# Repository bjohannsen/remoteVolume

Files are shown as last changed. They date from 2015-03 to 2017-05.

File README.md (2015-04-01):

# remoteVolume
An AVR-based IR controlled audio volume controller.
Primary purpose was to use active studio monitors with a TV without a fitting AV receiver.

# Features
* ATmega168 controller
* Volume controlling via <a href="http://www.ti.com/lit/ds/symlink/pga2311.pdf" target="_blank">TI PGA2311</a>
* Working with most IR protocols thanks to <a href="http://www.mikrocontroller.net/articles/IRMP" target="_blank">IRMP</a> library
* Two selectable input sources
* Switch output to control a subwoofer
* Display current volume by a ring of LEDs and a motorized pot.

#Caveats
* External power supply needed, for example <a href="http://www.meanwell.com/search/NET-35/NET-35-spec.pdf" target="_blank">Mean Well NET-35B</a>

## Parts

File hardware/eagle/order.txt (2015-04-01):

Parts
Front Panel:							
#	Value		Package		Reichelt
2	74HCT595N	DIL16    	74HC 595
16	1.5k		R-EU_0207/7	METALL 1,5K
1   	100		R-EU_0207/7	METALL 100
1   	MA10-2      	MA10-2		SL 2X10G 2,54
16	LED 3mm, low current		LED 3MM 2MA GN
1	TSOP1738	TSOP17XX	TSOP 31238

Main:
#	Value		Package		Reichelt
10      100n           	C025-025X050	X7R-2,5 100N
2	220u		E2,5-6		RAD FR 220/16
2	22p		C025-025X050	KERKO 22P
7	47u		E2,5-6		RAD FR 47/25
2	3.3n		C050-055X075	FKP-2 3,3N
2	470n		C5B3.5		MKS-2 470N
2	1000u		E3,5-8		RAD FR 1.000/10
2	100u		E2,5-5		RAD FR 100/16
11	--		NRJ4HF		NEUTRIK NR-J4HF
4	DIODE1N4148	DO-35		1N 4148
1	MEGA168-P	DIL28-3		ATMEGA 168-20DIP    
1	L293D		DIL16		L 293 D
1	7805		TO220V		µA 7805
1	7905		TO220V		µA 7905
1	OPA2132P	DIL08		OPA 2132 PA
1	PGA2311P	DIL16		(--> eBay)
1	--		1X04/90		MPE 087-1-004
1	AVR-ISP-10	1x10		WSL 10G
2	--		FTR-B4C		FTR-B4CA 4,5V
1	20MHz		HC49/S		20,0000-HC49U-S
2	10k		0207/7		METALL 10,0K
4	2k		0207/7		METALL 2,00K
2	220k		0207/7		METALL 220K
1	100k		0207/7		METALL 100K
2	27k		0207/7		METALL 27,0K
1	33		0207/7		METALL 33,0
1	--		FE10-2W		BL 2X10W 2,54
2	BC337		TO92		BC 337-40
1	--		RK16816MG	(--> conrad: 442068-62)
1	RCA-4-117-01	RCA-4-117-01	CBP 4
1	RCA-2		RCA-2		CBP 2

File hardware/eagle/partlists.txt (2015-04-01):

Parts
Front Panel:
IC1      74HCT595N      DIL16    
IC2      74HCT595N      DIL16    
R1       1.5k           0207/7 
R2       1.5k           0207/7 
R3       1.5k           0207/7 
R4       1.5k           0207/7 
R5       1.5k           0207/7
R6       1.5k           0207/7
R7       1.5k           0207/7
R8       1.5k           0207/7
R9       1.5k           0207/7
R10      1.5k           0207/7
R11      1.5k           0207/7
R12      1.5k           0207/7
R13      1.5k           0207/7
R14      1.5k           0207/7
R15      1.5k           0207/7
R16      1.5k           0207/7
R17      100            0207/7
SV2      --             MA10-2
U$2      --		16x3mm LED low current
U$3      TSOP1738       TSOP17XX

Main:
C1       100n           C025-025X050
C2       100n           C025-025X050
C3       220u           E2,5-6      
C4       22p            C025-025X050
C5       22p            C025-025X050
C6       100n           C025-025X050
C7       100n           C025-025X050
C8       47u            E2,5-6      
C9       100n           C025-025X050
C10      100n           C025-025X050
C11      3.3n           C050-055X075
C12      470n           C5B3.5      
C13      470n           C5B3.5      
C14      3.3n           C050-055X075
C15      220u           E2,5-6      
C16      1000u          E3,5-8      
C17      100n           C025-025X050
C18      100u           E2,5-5      
C19      100u           E2,5-5      
C20      100n           C025-025X050
C21      47u            E2,5-5      
C22      100u           E2,5-5      
C23      100n           C025-025X050
C24      47u            E2,5-5      
C25      100n           C025-025X050
C26      1000u          E3,5-8      
C28      47u            E2,5-5      
C29      47u            E2,5-5      
C30      47u            E2,5-5      
C31      47u            E2,5-5      
CN1      NRJ4HF         NRJ4HF      
D5       1N4148    	DO-35       
D6       1N4148         DO-35
D7       1N4148    	DO-35       
D8       1N4148         DO35
IC1      MEGA168-P	DIL28-3     
IC2      L293D          DIL16       
IC3      7805           TO220V      
IC4      OPA2132P       DIL08       
IC5      PGA2311P       DIL16       
IC7      7905           TO220V      
JP1      --             1X04/90     
JP4      --	    	AVR-ISP-10  
K1       --		FTR-B4C
K2       --		FTR-B4C
Q1       20MHz          HC49/S      
R2       10k            0207/7      
R4       2k             0207/7      
R6       2k             0207/7      
R7       220k           0207/7      
R8       220k           0207/7      
R9       2k             0207/7      
R10      100k           0207/7      
R11      27k            0207/7      
R12      2k             0207/7     
R13      27k            0207/7     
R14      39             0207/7     
R15      39             0207/7     
R16      10k            0207/7     
SV2      --             FE10-2W    
T2       BC337          TO92       
T3       BC337          TO92       
U$1      --		RK16816MG  
X_IN     --		RCA-4-117-01
X_OUT    --		RCA-2

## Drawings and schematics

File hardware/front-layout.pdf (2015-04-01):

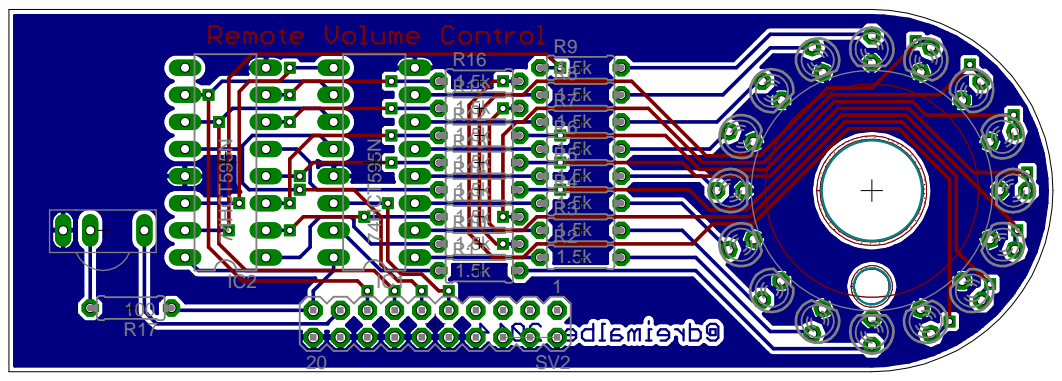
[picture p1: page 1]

1.5k R13 | R6 1.5k
1.5k R14 | 1.5k R5
R11 1.5k | R4 1.5k

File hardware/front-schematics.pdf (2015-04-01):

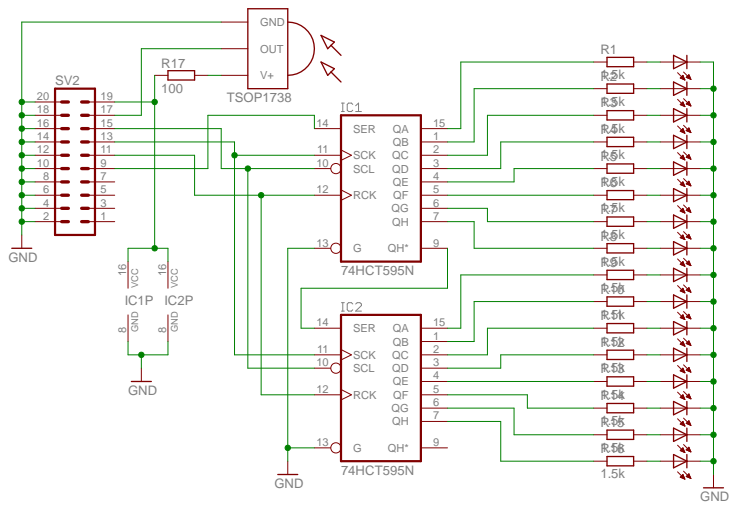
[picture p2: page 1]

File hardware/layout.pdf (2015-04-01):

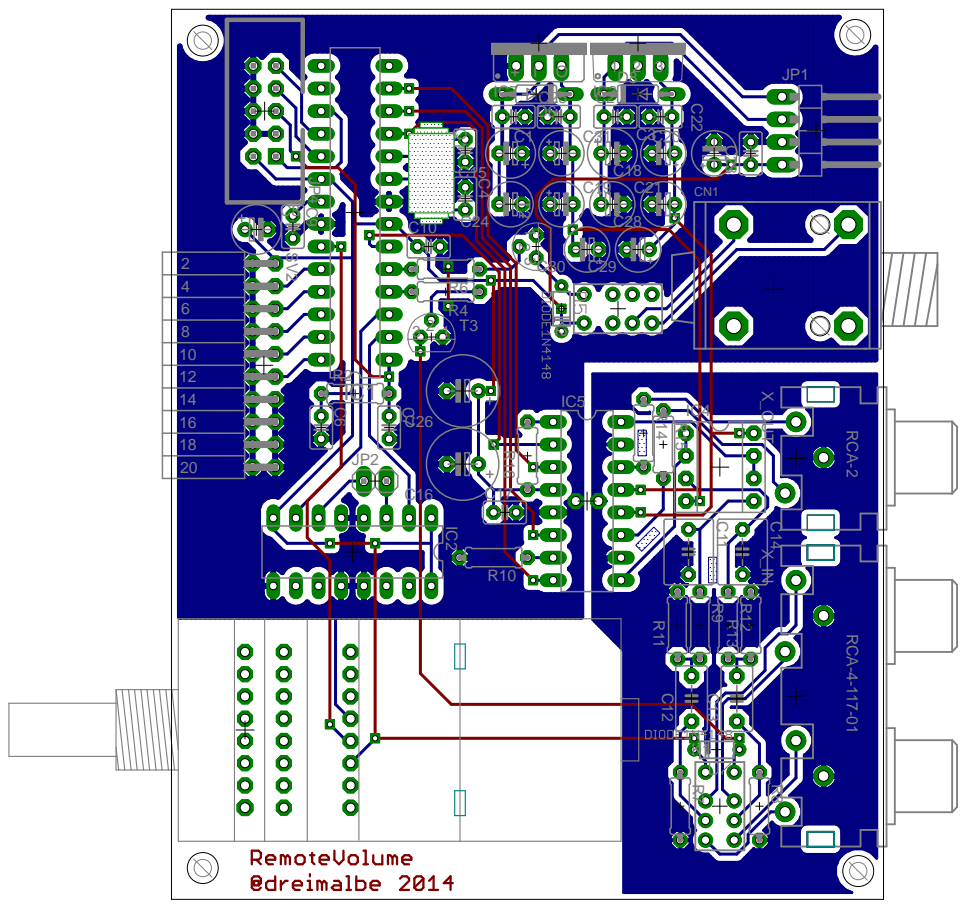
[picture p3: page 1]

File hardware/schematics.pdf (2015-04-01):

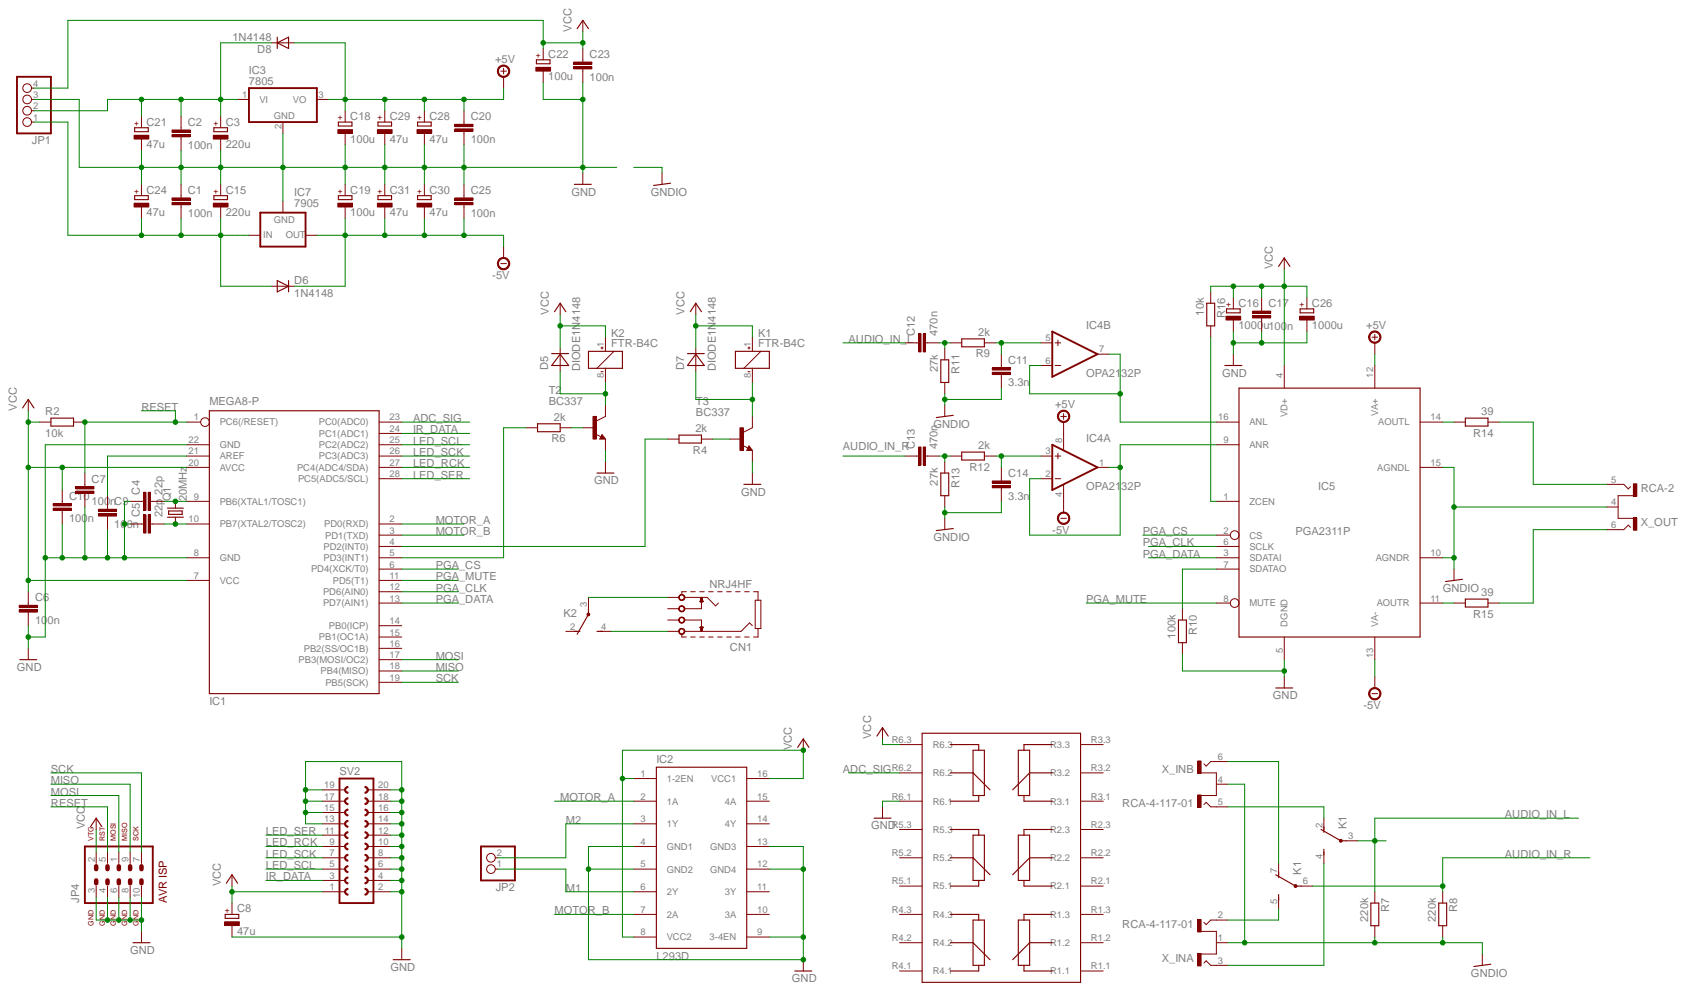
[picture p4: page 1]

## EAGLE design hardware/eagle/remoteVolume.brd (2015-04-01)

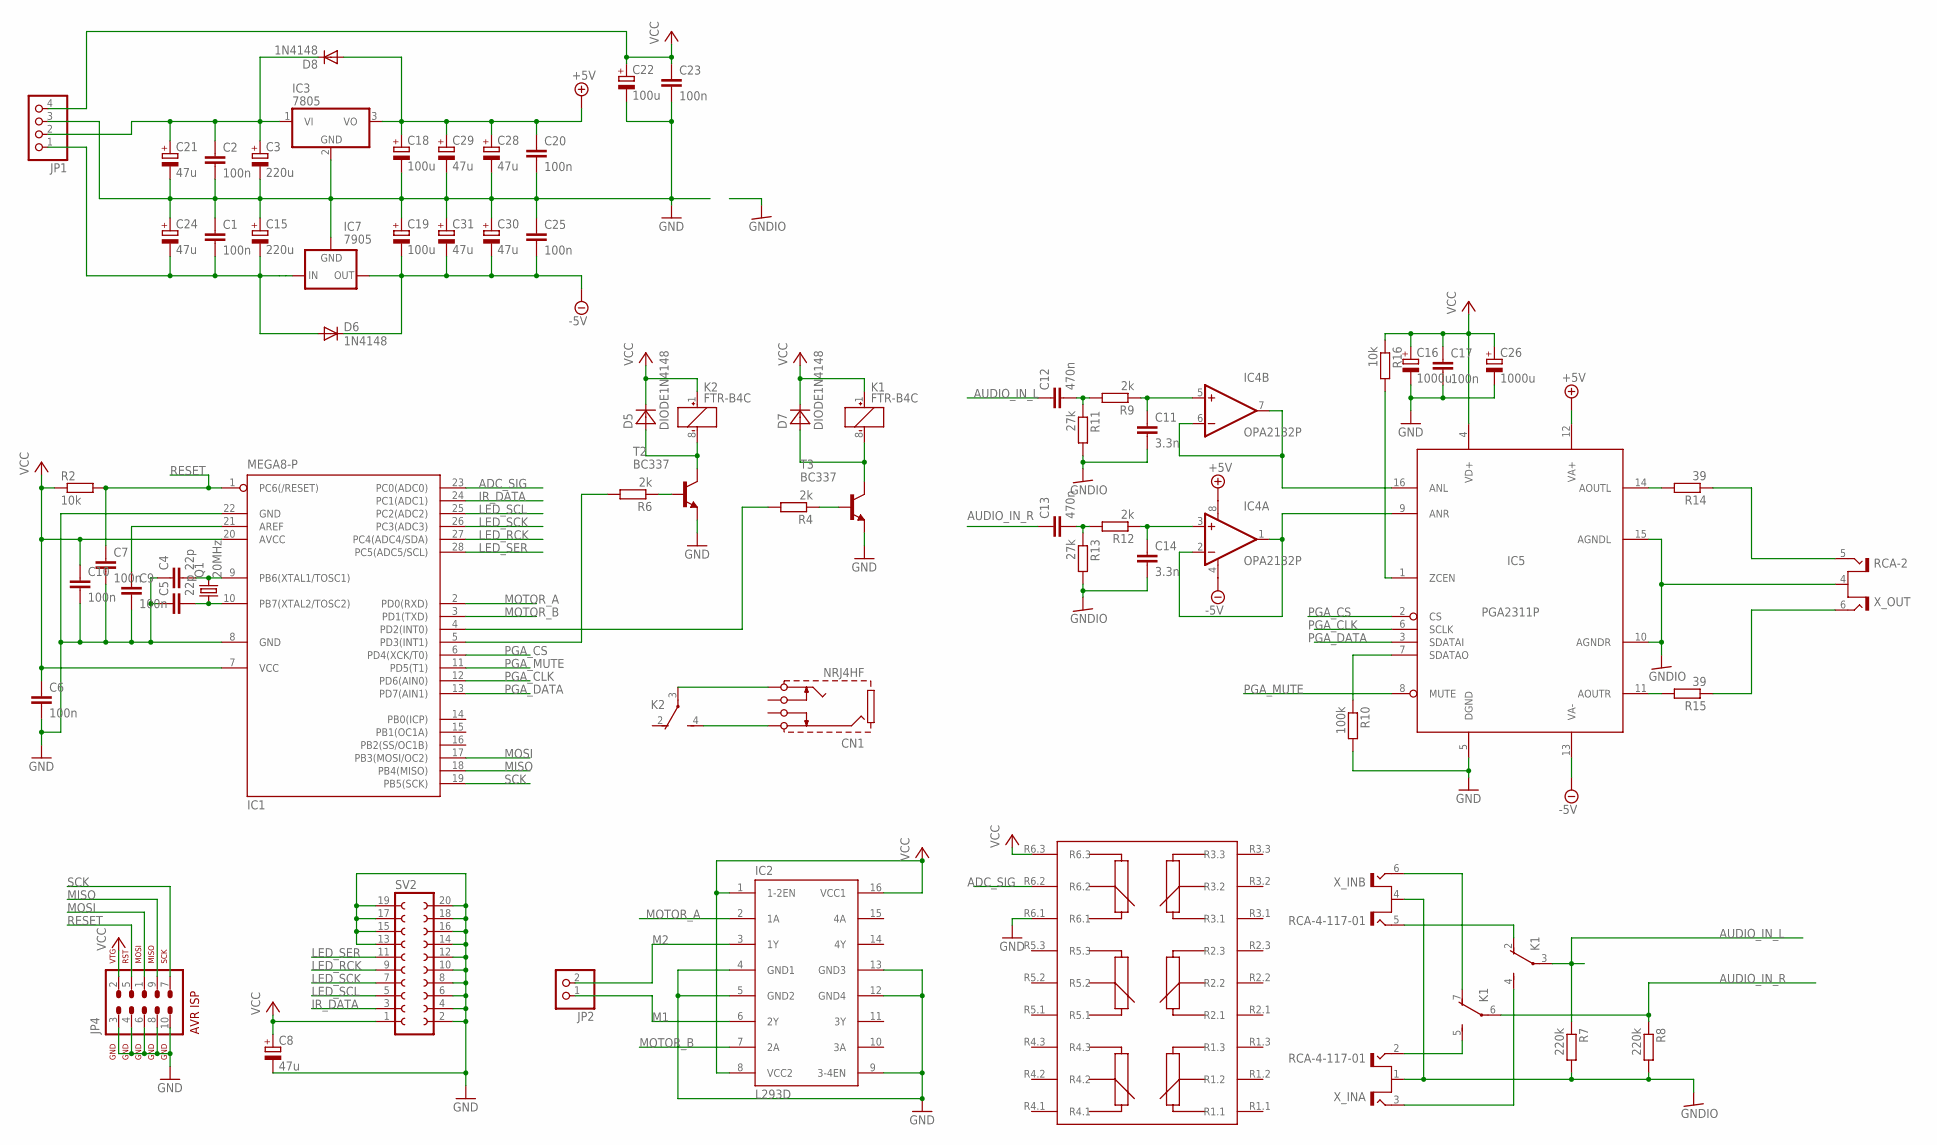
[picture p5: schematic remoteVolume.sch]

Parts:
C1, C2, C6, C7, C9, C10, C17, C20, C23, C25: 100n; C025-025X050
C3, C15: 220u; E2,5-6
C4, C5: 22p; C025-025X050
C8: 47u; E2,5-6
C11, C14: 3.3n; C050-055X075
C12, C13: 470n; C5B3.5
C16, C26: 1000u; E3,5-8
C18, C19, C22: 100u; E2,5-5
C21, C24, C28, C29, C30, C31: 47u; E2,5-5
CN1: NRJ4HF
D5, D7: DIODE1N4148; DO-35
D6, D8: 1N4148; DO35-7
IC1: MEGA8-P; DIL28-3
IC2: L293D; DIL16
IC3: 7805; TO220V
IC4: OPA2132P; DIL08
IC5: PGA2311P; DIL16
IC7: 7905; 79XXS
JP1: PINHD-1X4/90; 1X04/90
JP2: PINHD-1X2; 1X02
JP4: AVR-ISP-10
K1, K2: FTR-B4C
Q1: 20MHz; HC49/S
R2, R16: 10k; 0207/7
R4, R6, R9, R12: 2k; 0207/7
R7, R8: 220k; 0207/7
R10: 100k; 0207/7
R11, R13: 27k; 0207/7
R14, R15: 39; 0207/7
SV2: FE10-2W
T2, T3: BC337; TO92
U$1: RK16816MG
X_IN: RCA-4-117-01
X_OUT: RCA-2

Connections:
+5V: C18.+, C20.1, C28.+, C29.+, D8.A, IC3.3 (VO), IC4.8 (V+), IC5.12 (VA+)
-5V: C19.-, C25.2, C30.-, C31.-, D6.C, IC4.4 (V-), IC5.13 (VA-), IC7.OUT
ADC_SIG: IC1.23 (PC0(ADC0)), U$1.R6.2
AUDIO_IN_L: C12.1, K1.3, R7.1
AUDIO_IN_R: C13.1, K1.6, R8.1
GND: C1.1, C2.2, C3.-, C4.1, C5.1, C6.2, C7.2, C8.-, C9.2, C10.2, C15.+, C16.-, C17.2, C18.-, C19.+, C20.2, C21.-, C22.-, C23.2, C24.+, C25.1, C26.-, C28.-, C29.-, C30.+, C31.+, IC1.8 (GND), IC1.22 (GND), IC2.4 (GND1), IC2.5 (GND2), IC2.9 (3-4EN), IC2.12 (GND4), IC2.13 (GND3), IC3.2 (GND), IC5.5 (DGND), IC7.GND, JP1.3, JP4.3, JP4.4, JP4.6, JP4.8, JP4.10, R10.2, SV2.2, SV2.4, SV2.6, SV2.8, SV2.10, SV2.12, SV2.13, SV2.14, SV2.15, SV2.16, SV2.17, SV2.18, SV2.19, SV2.20, T2.1 (E), T3.1 (E), U$1.R6.1
GNDIO: C11.2, C14.2, IC5.10 (AGNDR), IC5.15 (AGNDL), R7.2, R8.2, R11.2, R13.2, X_IN.1 (S), X_IN.4 (S), X_OUT.4 (S)
IR_DATA: IC1.24 (PC1(ADC1)), SV2.3
LED_RCK: IC1.27 (PC4(ADC4/SDA)), SV2.9
LED_SCK: IC1.26 (PC3(ADC3)), SV2.7
LED_SCL: IC1.25 (PC2(ADC2)), SV2.5
LED_SER: IC1.28 (PC5(ADC5/SCL)), SV2.11
M1: IC2.6 (2Y), JP2.1
M2: IC2.3 (1Y), JP2.2
MISO: IC1.18 (PB4(MISO)), JP4.9
MOSI: IC1.17 (PB3(MOSI/OC2)), JP4.1
MOTOR_A: IC1.2 (PD0(RXD)), IC2.2 (1A)
MOTOR_B: IC1.3 (PD1(TXD)), IC2.7 (2A)
unnamed: CN1.SLEEVE, K2.4 (S)
unnamed: IC4.1 (OUT), IC4.2 (-IN), IC5.9 (ANR)
unnamed: C2.1, C3.+, C21.+, D8.C, IC3.1 (VI), JP1.2
unnamed: C1.2, C15.-, C24.-, D6.A, IC7.IN, JP1.1
unnamed: K1.5 (S), X_IN.2 (T1)
unnamed: D7.+, K1.8 (-), T3.3 (C)
unnamed: C4.2, IC1.9 (PB6(XTAL1/TOSC1)), Q1.2
unnamed: C5.2, IC1.10 (PB7(XTAL2/TOSC2)), Q1.1
unnamed: R4.1, T3.2 (B)
unnamed: IC1.4 (PD2(INT0)), R4.2
unnamed: K1.7 (O), X_IN.6 (T2)
unnamed: IC1.5 (PD3(INT1)), R6.2
unnamed: K1.2 (O), X_IN.5 (T1)
unnamed: R6.1, T2.2 (B)
unnamed: K1.4 (S), X_IN.3 (T2)
unnamed: D5.+, K2.8 (-), T2.3 (C)
unnamed: CN1.TIP, K2.3
unnamed: C9.1, IC1.21 (AREF)
unnamed: IC4.6 (-IN), IC4.7 (OUT), IC5.16 (ANL)
unnamed: C12.2, R9.2, R11.1
unnamed: C11.1, IC4.5 (+IN), R9.1
unnamed: C14.1, IC4.3 (+IN), R12.1
unnamed: R14.1, X_OUT.5 (T1)
unnamed: R15.1, X_OUT.6 (T2)
unnamed: C13.2, R12.2, R13.1
unnamed: IC5.7 (SDATAO), R10.1
unnamed: IC5.14 (AOUTL), R14.2
unnamed: IC5.11 (AOUTR), R15.2
unnamed: IC5.1 (ZCEN), R16.2
PGA_CLK: IC1.12 (PD6(AIN0)), IC5.6 (SCLK)
PGA_CS: IC1.6 (PD4(XCK/T0)), IC5.2 (CS)
PGA_DATA: IC1.13 (PD7(AIN1)), IC5.3 (SDATAI)
PGA_MUTE: IC1.11 (PD5(T1)), IC5.8 (MUTE)
RESET: C7.1, IC1.1 (PC6(/RESET)), JP4.5, R2.2
SCK: IC1.19 (PB5(SCK)), JP4.7
VCC: C6.1, C8.+, C10.1, C16.+, C17.1, C22.+, C23.1, C26.+, D5.-, D7.-, IC1.7 (VCC), IC1.20 (AVCC), IC2.1 (1-2EN), IC2.8 (VCC2), IC2.16 (VCC1), IC5.4 (VD+), JP1.4, JP4.2, K1.1 (+), K2.1 (+), R2.1, R16.1, SV2.1, U$1.R6.3

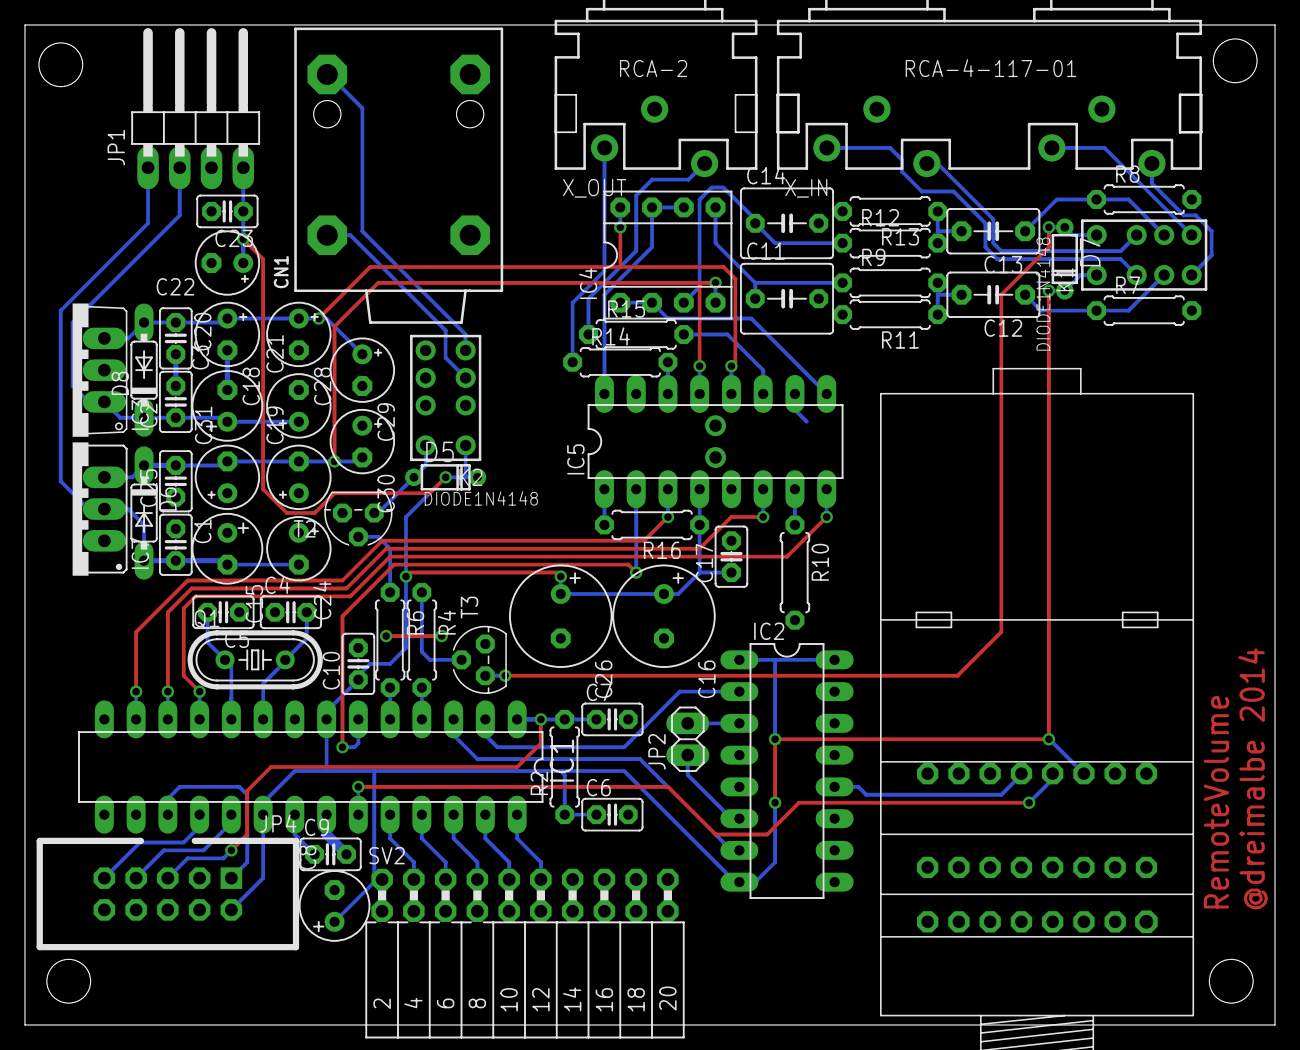
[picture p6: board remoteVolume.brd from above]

Board: 2 copper layers, 100.0 x 80.0 mm, 66 parts (0 on the bottom side), 54 nets.

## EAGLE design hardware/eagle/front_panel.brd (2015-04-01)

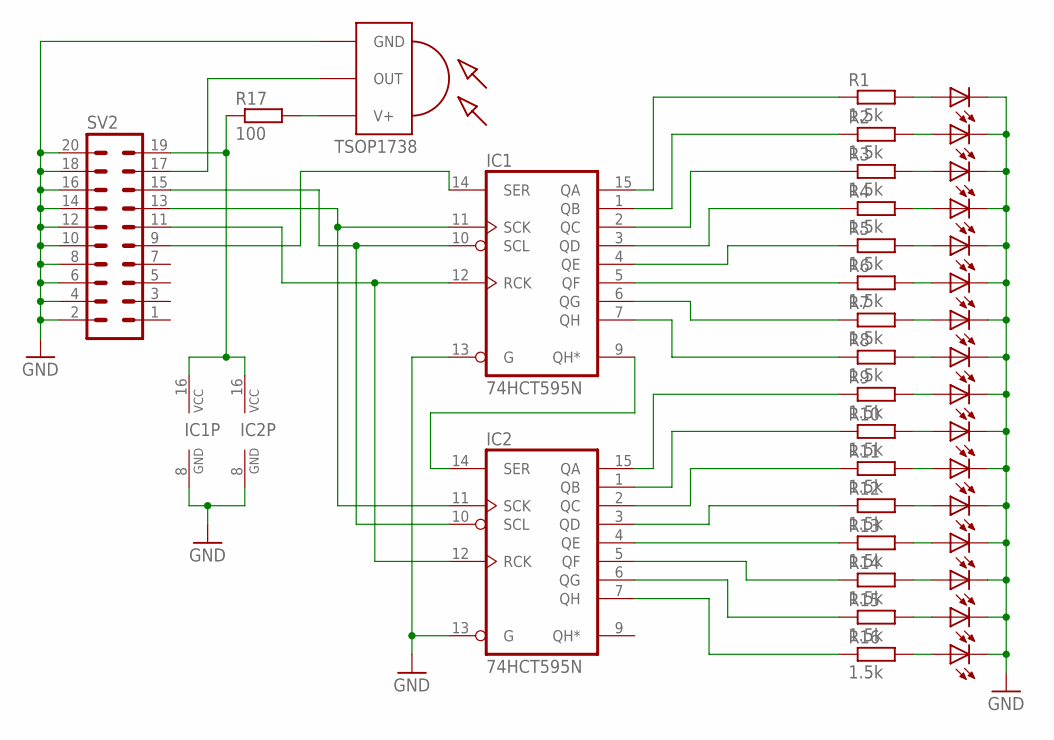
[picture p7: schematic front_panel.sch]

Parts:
IC1, IC2: 74HCT595N; DIL16
R1, R2, R3, R4, R5, R6, R7, R8, R9, R10, R11, R12, R13, R14, R15, R16: 1.5k; 0207/7
R17: 100; 0207/7
SV2: MA10-2
U$2: LED_RING_16; POTI_LED_RING16
U$3: TSOP1738; TSOP17XX

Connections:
GND: IC1.8 (GND), IC1.13 (G), IC2.8 (GND), IC2.13 (G), SV2.2, SV2.4, SV2.6, SV2.8, SV2.10, SV2.12, SV2.14, SV2.16, SV2.18, SV2.20, U$2.K0, U$2.K1, U$2.K2, U$2.K3, U$2.K4, U$2.K5, U$2.K6, U$2.K7, U$2.K8, U$2.K9, U$2.K10, U$2.K11, U$2.K12, U$2.K13, U$2.K14, U$2.K15, U$3.GND
unnamed: IC1.9 (QH*), IC2.14 (SER)
unnamed: R9.2, U$2.A8
unnamed: IC1.11 (SCK), IC2.11 (SCK), SV2.13
unnamed: IC1.10 (SCL), IC2.10 (SCL), SV2.15
unnamed: IC1.12 (RCK), IC2.12 (RCK), SV2.11
unnamed: IC1.14 (SER), SV2.9
unnamed: R1.2, U$2.A0
unnamed: R2.2, U$2.A1
unnamed: R3.2, U$2.A2
unnamed: R4.2, U$2.A3
unnamed: R5.2, U$2.A4
unnamed: R6.2, U$2.A5
unnamed: R7.2, U$2.A6
unnamed: R8.2, U$2.A7
unnamed: R10.2, U$2.A9
unnamed: R11.2, U$2.A10
unnamed: R12.2, U$2.A11
unnamed: R13.2, U$2.A12
unnamed: R14.2, U$2.A13
unnamed: R15.2, U$2.A14
unnamed: R16.2, U$2.A15
unnamed: IC1.15 (QA), R1.1
unnamed: IC1.1 (QB), R2.1
unnamed: IC1.2 (QC), R3.1
unnamed: IC1.3 (QD), R4.1
unnamed: IC1.7 (QH), R8.1
unnamed: IC1.6 (QG), R7.1
unnamed: IC1.5 (QF), R6.1
unnamed: IC1.4 (QE), R5.1
unnamed: IC2.15 (QA), R9.1
unnamed: IC2.1 (QB), R10.1
unnamed: IC2.2 (QC), R11.1
unnamed: IC2.3 (QD), R12.1
unnamed: IC2.7 (QH), R16.1
unnamed: IC2.6 (QG), R15.1
unnamed: IC2.5 (QF), R14.1
unnamed: IC2.4 (QE), R13.1
unnamed: SV2.17, U$3.OUT
unnamed: R17.2, U$3.V+
unnamed: IC1.16 (VCC), IC2.16 (VCC), R17.1, SV2.19

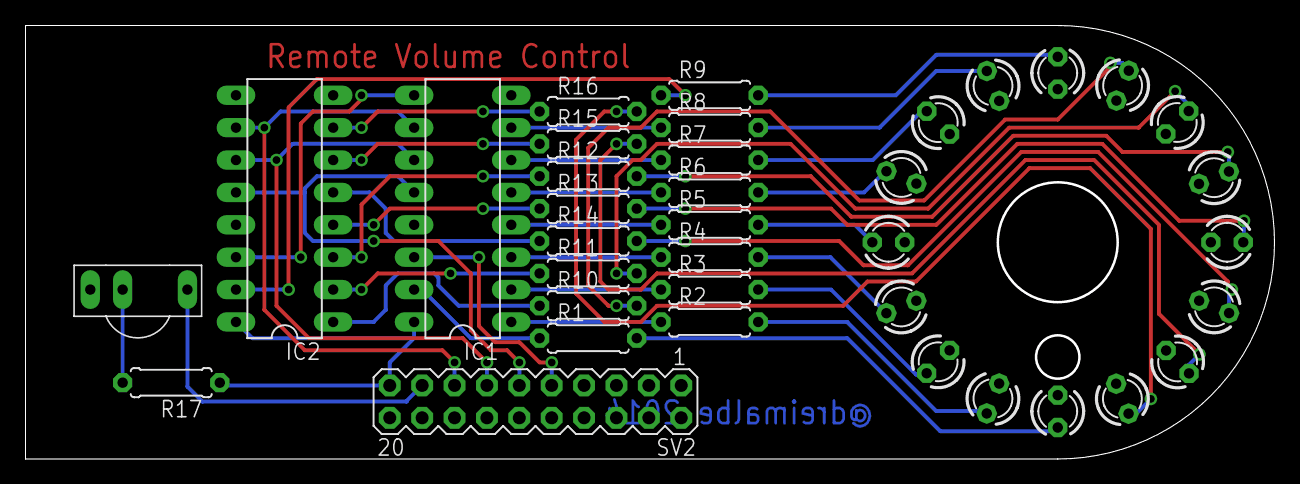
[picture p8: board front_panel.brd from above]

Board: 2 copper layers, 98.0 x 34.0 mm, 22 parts (0 on the bottom side), 41 nets.

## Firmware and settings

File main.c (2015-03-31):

#include "volumeRemote.h"

// VolumeRemote Definitions
uint8_t _state = 0x0;
uint8_t _flags = 0x0;
uint8_t _submute_counter = 0;
uint8_t _gain_level = GAIN_STARTUP_STEP;

// Timer Interrupt
ISR(TIMER0_COMPA_vect)
{
	static uint8_t sw_timer=0;

	if(_submute_counter > 0)
	{
		_submute_counter--;
		if(_submute_counter==0) {
			RELAY_SUBMUTE_OPEN;
		}
	}

	if(sw_timer&0x01)
	{
		_flags |= FLAG_LED_ANIMATION;
	}
	sw_timer++;

	_flags |= FLAG_CHECK_MOTOR_POSTION;
}

void update_pga_gain()
{
	pga_set_gain(pga_get_gain_for_level(_gain_level));
}

void toggle_mute()
{
	if(_state & STATE_MUTE)
	{
		_state &= ~STATE_MUTE;
		pga_unmute();
		leds_clear_state_muted();
		leds_set_animation(LEDS_ANIMATION_UNMUTE);
	}
	else
	{
		_state |= STATE_MUTE;
		pga_mute();
		leds_set_state_muted();
		leds_set_animation(LEDS_ANIMATION_MUTE);
	}
}

void toggle_source()
{
	if(_state & STATE_SECOND_SOURCE)
	{
		_state &= ~STATE_SECOND_SOURCE;
		RELAY_SOURCE_OPEN;
		leds_clear_second_source();
	}
	else
	{
		_state |= STATE_SECOND_SOURCE;
		RELAY_SOURCE_CLOSE;
		leds_set_second_source();
	}
}

void toggle_submute()
{
	RELAY_SUBMUTE_CLOSE;
	_submute_counter = RELAY_SUBMUTE_DELAY;
}

void turn_volume_up()
{
	if(_gain_level < GAIN_STEPS)
	{
		_gain_level++;
		update_pga_gain();
		leds_set_animation(LEDS_ANIMATION_VOL_UP);
		_flags |= FLAG_CALC_MOTOR_TARGET;
	}
}

void turn_volume_down()
{
	if(_gain_level > 0)
	{
		_gain_level--;
		update_pga_gain();
		leds_set_animation(LEDS_ANIMATION_VOL_DOWN);
		_flags |= FLAG_CALC_MOTOR_TARGET;
	}
}

void rx_led_callback(uint8_t on)
{
	leds_rx();
}

void init_io() {
    RELAY_DDR |= (RELAY_SOURCE|RELAY_SUBMUTE);
}

void init_volume_timer() {
	TCCR0A = (1<<WGM01);
	TCCR0B |= (1<<CS02|1<<CS00);
	OCR0A = 196;
	TIMSK0 |= (1<<OCIE0A);
}

int main (void)
{
    init_volume_timer();
    init_io();

    motor_init();
    pga_init();
    leds_init(GAIN_STEPS);
    receiver_init(rx_led_callback);

    update_pga_gain();
    pga_unmute();
    motor_update_target(_gain_level);

    sei();

    for(;;)
    {
    	uint8_t command = receiver_get_command();
        if(command)
        {
        	if(command == RECEIVER_COMMAND_VOLUME_UP)
        	{
        		turn_volume_up();
        	}
        	else if(command == RECEIVER_COMMAND_VOLUME_DOWN)
        	{
        		turn_volume_down();
        	}
        	else if(command == RECEIVER_COMMAND_TOGGLE_MUTE)
        	{
        		toggle_mute();
        	}
        	else if(command == RECEIVER_COMMAND_TOGGLE_SUBWOOFER)
        	{
        		toggle_submute();
        	}
        	else if(command == RECEIVER_COMMAND_TOGGLE_SOURCE)
        	{
        		toggle_source();
        	}
        }

        if(_flags & FLAG_CALC_MOTOR_TARGET)
        {
        	motor_update_target(_gain_level);
        	_flags &= ~FLAG_CALC_MOTOR_TARGET;
        }
        else if(_flags & FLAG_LED_ANIMATION)
        {
    		leds_animate(_gain_level);
        	_flags &= ~FLAG_LED_ANIMATION;
        }
        else if(_flags & FLAG_CHECK_MOTOR_POSTION)
        {
        	motor_check_position(adc_get_value(0));
        	_flags &= ~FLAG_CHECK_MOTOR_POSTION;
        }
    }
}

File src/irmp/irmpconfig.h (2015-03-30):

/*---------------------------------------------------------------------------------------------------------------------------------------------------
 * irmpconfig.h
 *
 * DO NOT INCLUDE THIS FILE, WILL BE INCLUDED BY IRMP.H!
 *
 * Copyright (c) 2009-2013 Frank Meyer - frank(at)fli4l.de
 *
 * $Id: irmpconfig.h,v 1.98 2013/01/17 07:33:13 fm Exp $
 *
 * ATMEGA88 @ 8 MHz
 *
 * This program is free software; you can redistribute it and/or modify
 * it under the terms of the GNU General Public License as published by
 * the Free Software Foundation; either version 2 of the License, or
 * (at your option) any later version.
 *---------------------------------------------------------------------------------------------------------------------------------------------------
 */

#ifndef _IRMPCONFIG_H_
#define _IRMPCONFIG_H_

#ifndef _IRMP_H_
#  error please include only irmp.h, not irmpconfig.h
#endif

/*---------------------------------------------------------------------------------------------------------------------------------------------------
 * Change F_INTERRUPTS if you change the number of interrupts per second,
 * Normally, F_INTERRUPTS should be in the range from 10000 to 15000, typical is 15000
 * A value above 15000 costs additional program space, absolute maximum value is 20000.
 *---------------------------------------------------------------------------------------------------------------------------------------------------
 */
#ifndef F_INTERRUPTS
#  define F_INTERRUPTS                          15000   // interrupts per second, min: 10000, max: 20000, typ: 15000
#endif

/*---------------------------------------------------------------------------------------------------------------------------------------------------
 * Change settings from 1 to 0 if you want to disable one or more decoders.
 * This saves program space.
 *
 * 1 enable  decoder
 * 0 disable decoder
 *
 * The standard decoders are enabled per default.
 * Less common protocols are disabled here, you need to enable them manually.
 *
 * If you want to use FDC or RCCAR simultaneous with RC5 protocol, additional program space is required.
 * If you don't need RC5 when using FDC/RCCAR, you should disable RC5.
 * You cannot enable both DENON and RUWIDO, only enable one of them.
 *---------------------------------------------------------------------------------------------------------------------------------------------------
 */

// typical protocols, disable here!             Enable  Remarks                 F_INTERRUPTS            Program Space
#define IRMP_SUPPORT_SIRCS_PROTOCOL             0       // Sony SIRCS           >= 10000                 ~150 bytes
#define IRMP_SUPPORT_NEC_PROTOCOL               0       // NEC + APPLE          >= 10000                 ~300 bytes
#define IRMP_SUPPORT_SAMSUNG_PROTOCOL           1       // Samsung + Samsung32  >= 10000                 ~300 bytes
#define IRMP_SUPPORT_MATSUSHITA_PROTOCOL        0       // Matsushita           >= 10000                  ~50 bytes
#define IRMP_SUPPORT_KASEIKYO_PROTOCOL          0       // Kaseikyo             >= 10000                 ~250 bytes
#define IRMP_SUPPORT_DENON_PROTOCOL             0       // DENON, Sharp         >= 10000                 ~250 bytes

// more protocols, enable here!                 Enable  Remarks                 F_INTERRUPTS            Program Space
#define IRMP_SUPPORT_RC5_PROTOCOL               0       // RC5                  >= 10000                 ~250 bytes
#define IRMP_SUPPORT_RC6_PROTOCOL               0       // RC6 & RC6A           >= 10000                 ~250 bytes
#define IRMP_SUPPORT_JVC_PROTOCOL               0       // JVC                  >= 10000                 ~150 bytes
#define IRMP_SUPPORT_NEC16_PROTOCOL             0       // NEC16                >= 10000                 ~100 bytes
#define IRMP_SUPPORT_NEC42_PROTOCOL             0       // NEC42                >= 10000                 ~300 bytes
#define IRMP_SUPPORT_IR60_PROTOCOL              0       // IR60 (SDA2008)       >= 10000                 ~300 bytes
#define IRMP_SUPPORT_GRUNDIG_PROTOCOL           0       // Grundig              >= 10000                 ~300 bytes
#define IRMP_SUPPORT_SIEMENS_PROTOCOL           0       // Siemens Gigaset      >= 15000                 ~550 bytes
#define IRMP_SUPPORT_NOKIA_PROTOCOL             0       // Nokia                >= 10000                 ~300 bytes
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

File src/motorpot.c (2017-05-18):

/*
 * motorpot.c
 *
 * Controlling of motorpot.
 *
 * Author: @dreimalbe
 */
#include "motorpot.h"

uint16_t _motor_target = 0;

uint8_t motor_calc_adc_tolerance(uint16_t adc_value)
{
	double tolerance = (double)adc_value*MOTOR_ADC_TOLERANCE;
	return (uint8_t) tolerance+1;
}

void motor_check_position(uint16_t adc_value)
{
	uint8_t adc_tolerance = motor_calc_adc_tolerance(adc_value);

	MOTOR_STOP;
	if(adc_value > _motor_target+adc_tolerance)
	{
		MOTOR_RUN_CW;
	}
	// here is wrap around trouble if _motor_target < 0.
	//else if(adc_value < _motor_target-adc_tolerance)
	else if(_motor_target > adc_tolerance && adc_value < _motor_target-adc_tolerance)
	{
		MOTOR_RUN_CCW;
	}
}

void motor_init() {
    MOTOR_DDR |= (MOTOR_A|MOTOR_B);
}

void motor_update_target(uint8_t gain_level)
{
	double base = 0.4763 * (double)gain_level;
	_motor_target = pow(base, 2.3);
}

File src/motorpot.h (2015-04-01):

/*
 * motorpot.h
 *
 * Author: @dreimalbe
 */
#ifndef MOTORPOT_H_
#define MOTORPOT_H_

#include <math.h>
#include <avr/io.h>
#include <stdio.h>

#define MOTOR_PORT				PORTD
#define MOTOR_DDR				DDRD
#define MOTOR_B					(1<<PORTD0)
#define MOTOR_A					(1<<PORTD1)

#define MOTOR_ADC_TOLERANCE 	0.1

#define MOTOR_STOP				(MOTOR_PORT &= ~(MOTOR_A | MOTOR_B))
#define MOTOR_RUN_CW			(MOTOR_PORT |= MOTOR_A)
#define MOTOR_RUN_CCW			(MOTOR_PORT |= MOTOR_B)

void motor_check_position(uint16_t adc_value);
void motor_init();
void motor_update_target(uint8_t gain_level);


#endif /* MOTORPOT_H_ */

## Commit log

2015-03-31 Refactored motor pot logic to own source file.
2015-03-31 Refactored relay controlling.
2015-04-01 Added hardware shematics and layouts.
    [front_panel.brd, front_panel.sch, remoteVolume.brd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]
2015-04-01 Reorganized project structure.
    [front_panel.brd, front_panel.sch, remoteVolume.brd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]
2017-05-18 Added makeup gain for second source. Switch source on remote power button.

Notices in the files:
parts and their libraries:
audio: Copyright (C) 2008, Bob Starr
